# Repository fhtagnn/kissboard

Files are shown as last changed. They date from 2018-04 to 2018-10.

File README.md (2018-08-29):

# kissboard
Hardware and Firmware for the Kissboard keyboard concept by urac/wolf (AdNW user community).

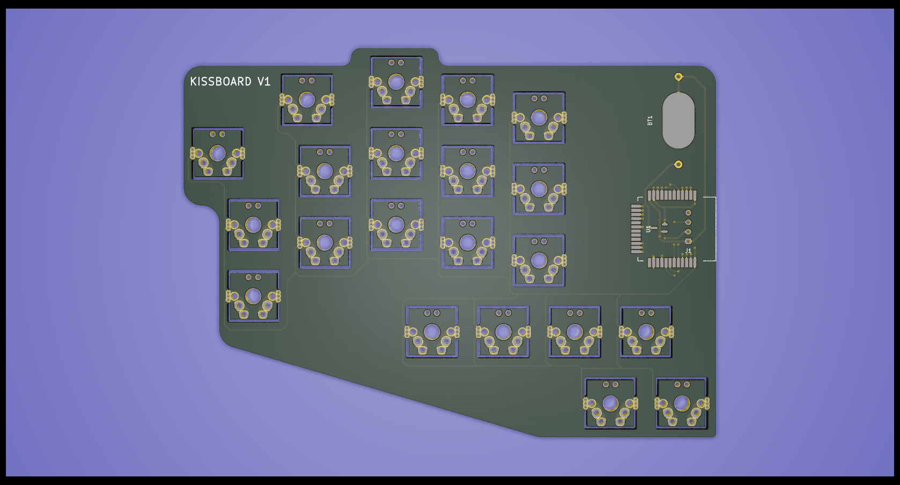
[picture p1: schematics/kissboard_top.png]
Kissboard top view PCB top view
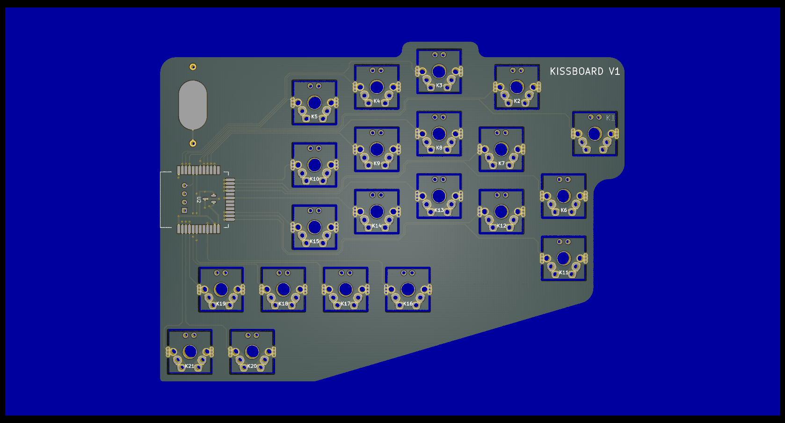
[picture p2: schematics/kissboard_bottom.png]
Kissboard bottom view PCB bottom view


PUQ Layout PUQ Layout overview (http://www.keyboard-layout-editor.com/#/gists/677e3572594a5fb39421fa693f03da17)

Layout explanation
* Middle label: standard tap output
* Bottom Label: double tap output
* Top Label: hold modifier
* Corner labels: Layers

## The idea
The physical key layout is inspired by a 2012 discussion on the german [neo user mailinglist](http://narkive.com/9UhJnT14) about custom keyboards using the [AdNW layout](http://www.adnw.de/). Specifically user urac proposed a minimalistic approach (KISS=keep it stupid simple) simply named [kissboard](https://docs.google.com/document/d/1TQ_BZYoZRW-ZFIaiolPAr9yNul6SBKypeA4ataw5Tz4/edit). Later, AdNW user wolf build a handwired custom board using a modified AdNW variant called PUQ discussed [here](https://groups.google.com/forum/#!topic/adnw/NdMOlERoFa4).

## PCB design
The PCB design was inspired by the [Mitosis Project](https://imgur.com/a/mwTFj) and its [Mitosis hardware](https://github.com/reversebias/mitosis-hardware) created by [reversebias](https://github.com/reversebias). Software implementation is a slightly modified copy of the [Mitosis Firmware](https://github.com/reversebias/mitosis) using [QMK](https://github.com/qmk/qmk_firmware/tree/master/keyboards/mitosis). The original Mitosis design is only available as an altium designer project. I used the freely available [KiCad](http://kicad-pcb.org/) and the converter [altium2kicad](https://github.com/thesourcerer8/altium2kicad) to first convert the layout to kicad, then create footprints of all important components and rebuild the design according to the kissboard/wolf switch layout.

## Firmware
The [Kissboard firmware](https://github.com/fhtagnn/mitosis) is a fork of the [Original Mitosis firmware](https://github.com/reversebias/mitosis) modified to reflect the pin connections used in this layout. Also, I use a [QMK Fork](https://github.com/fhtagnn/qmk_firmware) to implement any changes in the layout.

## Build Log
[Incomplete build log](https://imgur.com/a/pN4dOZB "Imgur Album")

# How to build
## Hardware
Source materials using the information in the BOM folder. Wait...build! :D

## Software
QMK can be build via Docker (below windows call) or per QMK instructions

```docker run -e keymap=default -e keyboard=ergodox_ez --rm -v PATHtoQMK:/qmk:rw edasque/qmk_firmware```

Firmware can be build via Docker (below windows call) or using any arm-gcc build environment. Follow instructions in firmware folder.

```docker run -it -v PATHtoFIRMWARE:/work/kissboard/:rw fhtagnn/kissboard_firmware```

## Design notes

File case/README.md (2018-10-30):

# Kisscase
A 3D printable case for the kissboard made with freecad. Currently two variants are planned: simple and "complex". The simple variant is currently work in progress. The complex one just a concept.

# Simple Variant
The simple variant is meant to work with the V1.0 of the kissboard without any holes for mounting and uses a very simple "clamp" to fix the board in a base.
Kisscase rendering kisscase first render

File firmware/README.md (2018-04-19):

# kissboard Keyboard Firmware
Firmware for Nordic MCUs used in the kissboard Keyboard that is a derivative of the [Mitosis concept](https://github.com/reversebias/mitosis) originally developed by [reversebias](https://github.com/reversebias)

This folder contains sources buildable with the Nordic SDK. To ease building under Windows a Dockerfile is included in the root directory of this repository. It already includes all the steps below including the modification of the SDK file. Usage is very simple if docker is installed. Open a console (Powershell) and type

```docker
docker run -it -v C:\PATH\kissboard\firmware:/work/kissboard/:rw fhtagnn/kissboard_firmware
```

PATH should point to your local copy of the repository. Then 

```
cd kissboard/kissboard-keyboard-basic/custom/armgcc/
make
```

to build the firmware for one of the halves (check config.h). The receiver firmware can be build accordingly.

## Install dependencies

Tested on Ubuntu 16.04.2, but should be able to find alternatives on all distros. 

```
sudo apt install openocd gcc-arm-none-eabi
```

## Download Nordic SDK

Nordic does not allow redistribution of their SDK or components, so download and extract from their site:

https://www.nordicsemi.com/eng/nordic/Products/nRF5-SDK/nRF5-SDK-v12-zip/54291

Firmware written and tested with version 11

```
unzip nRF5_SDK_11.0.0_89a8197.zip  -d nRF5_SDK_11
cd nRF5_SDK_11
```

## Toolchain set-up

A cofiguration file that came with the SDK needs to be changed. Assuming you installed gcc-arm with apt, the compiler root path needs to be changed in /components/toolchain/gcc/Makefile.posix, the line:
```
GNU_INSTALL_ROOT := /usr/local/gcc-arm-none-eabi-4_9-2015q1
```
Replaced with:
```
GNU_INSTALL_ROOT := /usr/
```

## Clone repository
Inside nRF5_SDK_11/
```
git clone https://github.com/fhtagnn/kissboard
```

## Install udev rules
```
sudo cp kissboard/firmware/49-stlinkv2.rules /etc/udev/rules.d/
```
Plug in, or replug in the programmer after this.

## OpenOCD server
The programming header on the side of the keyboard, from top to bottom:
```
SWCLK
SWDIO
GND
3.3V
```
It's best to remove the battery during long sessions of debugging, as charging non-rechargeable lithium batteries isn't recommended.

Launch a debugging session with:
```
openocd -f kissboard/firmware/nrf-stlinkv2.cfg
```
Should give you an output ending in:
```
Info : nrf51.cpu: hardware has 4 breakpoints, 2 watchpoints
```
Otherwise you likely have a loose or wrong wire.

## Manual programming
From the factory, these chips need to be erased:
```
echo reset halt | telnet localhost 4444
echo nrf51 mass_erase | telnet localhost 4444
```
From there, the precompiled binaries can be loaded:
```
echo reset halt | telnet localhost 4444
echo flash write_image `readlink -f precompiled-basic-left.hex` | telnet localhost 4444
echo reset | telnet localhost 4444
```

## Automatic make and programming scripts
To use the automatic build scripts:
```
cd kissboard/firmware/kissboard-keyboard-basic
./program.sh
```
An openocd session should be running in another terminal, as this script sends commands to it.

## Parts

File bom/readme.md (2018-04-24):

# Parts list
Parts required for the kissboard Keyboard

## Keyboard

Line | Description | Quantity | Links
--- | --- | --- | ---
1 | kissboard Keyboard PCB | 4 | [files](https://github.com/fhtagnn/kissboard/tree/master/gerber), [ordering](https://pcbshopper.com)
2 | Core51822 (B) Module | 2 | [direct](http://www.waveshare.com/core51822-b.htm), [aliexpress](https://www.aliexpress.com/w/wholesale-core51822-b.html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)
3 | Si2302 (or any other pin-compatible low voltage nFET) | 2 | [ebay](http://www.ebay.com/sch/i.html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), [digikey](https://www.digikey.com/product-detail/en/vishay-siliconix/SI2302CDS-T1-E3/SI2302CDS-T1-E3CT-ND/3305362)
4 | Right angle 0.1" header (for optional programming header) | 2x 4pin | 
5 | Straight 0.1" header (for battery stabilisers) | 4x 1pin | 
6 | CR2032 Battery | 2 | 
7 | Cherry MX or compatible switches | 46 |
8 | Keycaps | 46x 1U | 

## Receiver
Line | Description | Quantity | Links
--- | --- | --- | ---
1 | Receiver Interface PCB | 1 | [files](https://github.com/reversebias/mitosis-hardware/tree/master/gerbers), [ordering](https://pcbshopper.com)
2 | Core51822 (B) Module | 1 | [direct](http://www.waveshare.com/core51822-b.htm), [aliexpress](https://www.aliexpress.com/w/wholesale-core51822-b.html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)
3 | Arduino Pro Micro | 1 | 
4 | Cree CLVBA-FKA (or any other pin-compatible PLCC-4 LED) | 1 | [digikey](https://www.digikey.com/product-detail/en/cree-inc/CLVBA-FKA-CAEDH8BBB7A363/CLVBA-FKA-CAEDH8BBB7A363CT-ND/2650500)
5 | 1117 3.3v regulator in SOT223 (many types available) | 1 | [digikey](https://www.digikey.com/product-detail/en/diodes-incorporated/AZ1117IH-3.3TRG1/AZ1117IH-3.3TRG1DICT-ND/5699682)
6 | 1206 4.7k resistor array | 2 | [digikey](https://www.digikey.com/product-detail/en/stackpole-electronics-inc/RAVF164DJT4K70/RAVF164DJT4K70CT-ND/2425255)
7 | SMD tactile button (many compatible) | 2 | [digikey](https://www.digikey.com/product-detail/en/c-k/PTS525SM15SMTR2-LFS/CKN9104CT-ND/1146923)
8 | Right angle 0.1" header (for optional programming header) | 1x 4pin | 
9 | Straight 0.1" header (for stacking boards) | 2x 6pin |

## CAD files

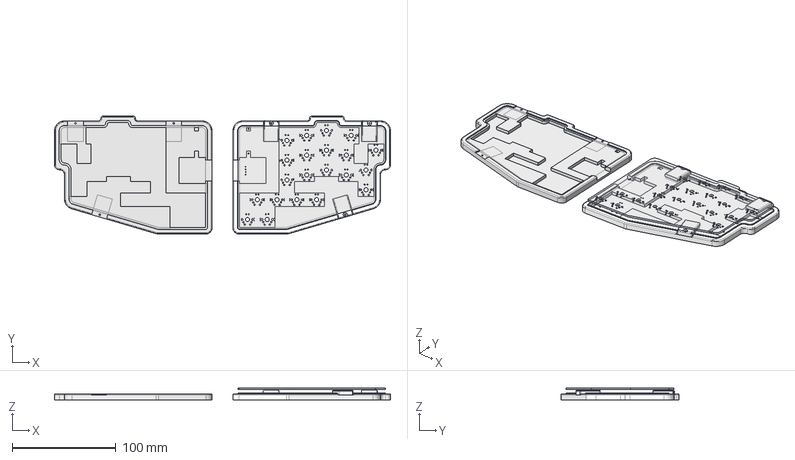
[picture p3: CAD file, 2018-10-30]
case/kisscase_simple_assembly.FCStd
323.6 x 113.7 x 11.7 mm
kisscase_base_right
kissboard_bottom_pcb
kisscase_clamp1
kisscase_clamp002
kisscase_clamp003
kissboard_top_pcb
kisscase_base_left

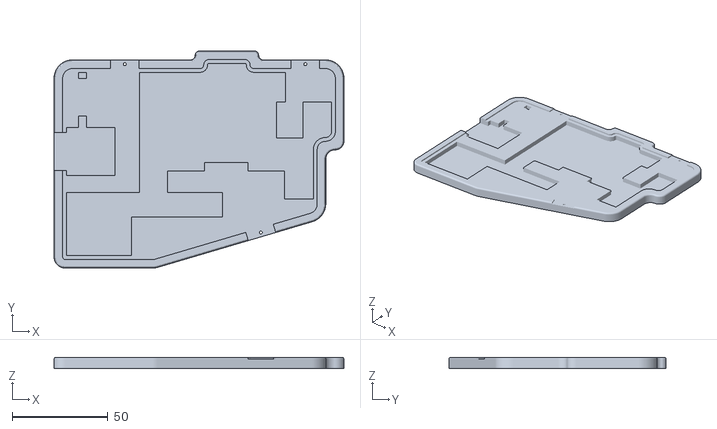
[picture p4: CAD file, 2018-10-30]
case/kisscase_right.stl
151.8 x 113.7 x 6.00

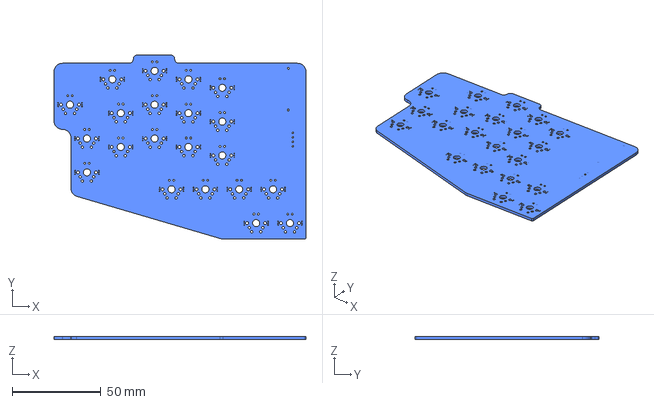
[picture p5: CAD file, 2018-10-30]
kicad-layout/kissboard.step
141.9 x 103.7 x 1.60 mm
Pcb
Step_Models

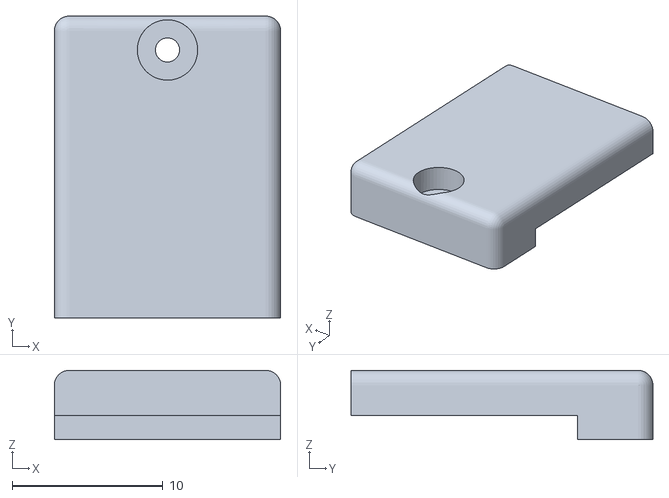
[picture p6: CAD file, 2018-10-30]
case/kisscase_clamp.stl
15.0 x 20.0 x 4.60

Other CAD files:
case/kisscase_left.stl
case/kisscase_simple_both halves.FCStd
case/kisscase_simple_clamp.FCStd

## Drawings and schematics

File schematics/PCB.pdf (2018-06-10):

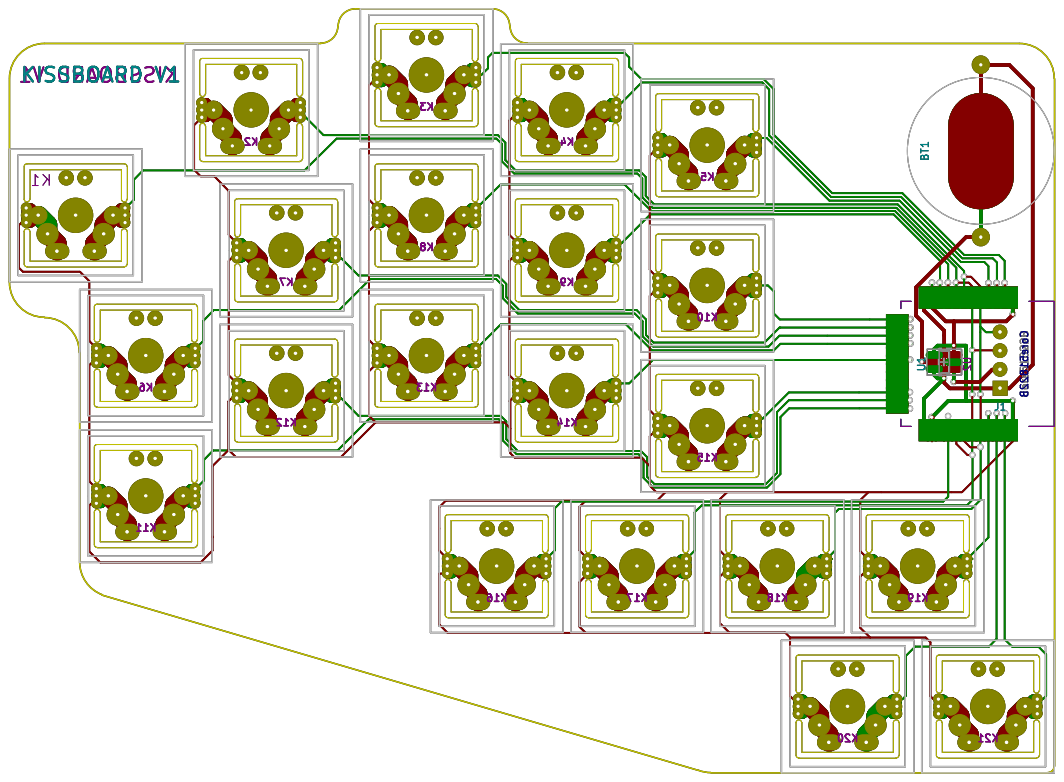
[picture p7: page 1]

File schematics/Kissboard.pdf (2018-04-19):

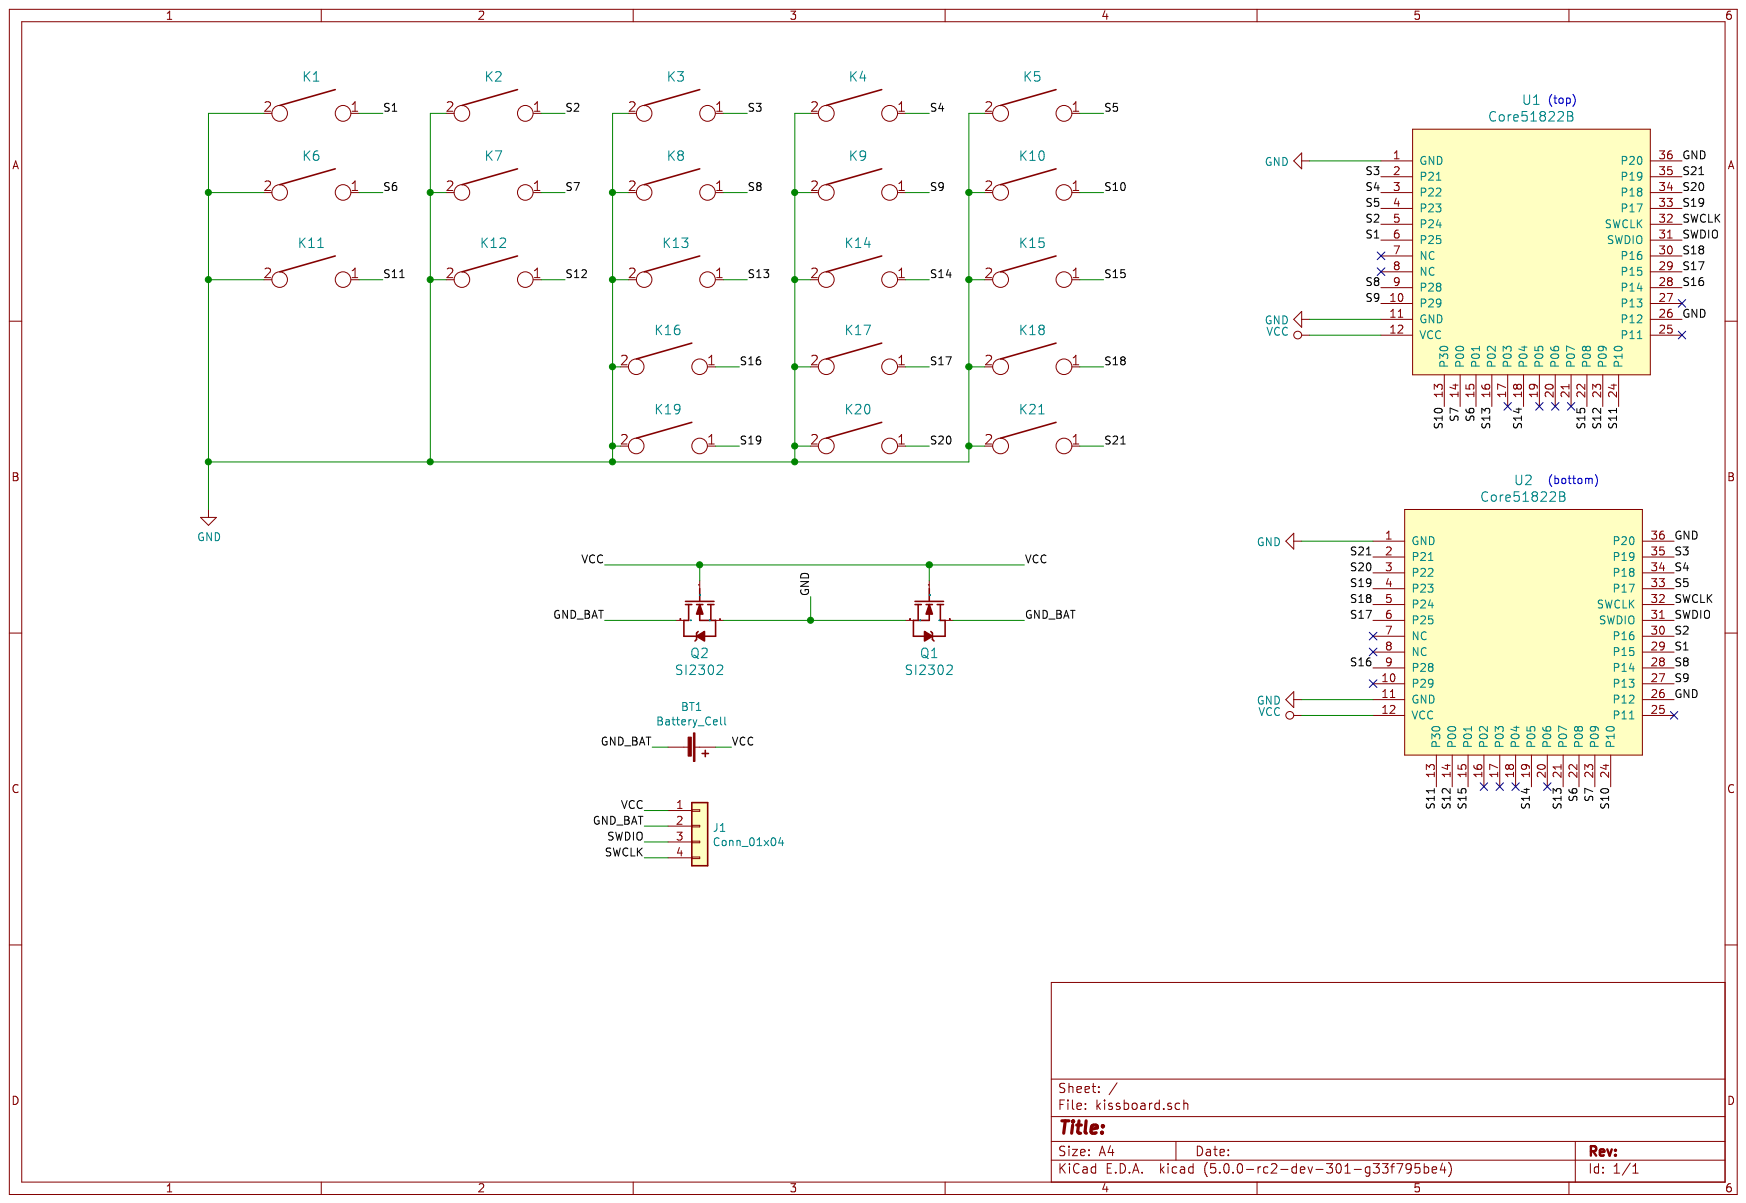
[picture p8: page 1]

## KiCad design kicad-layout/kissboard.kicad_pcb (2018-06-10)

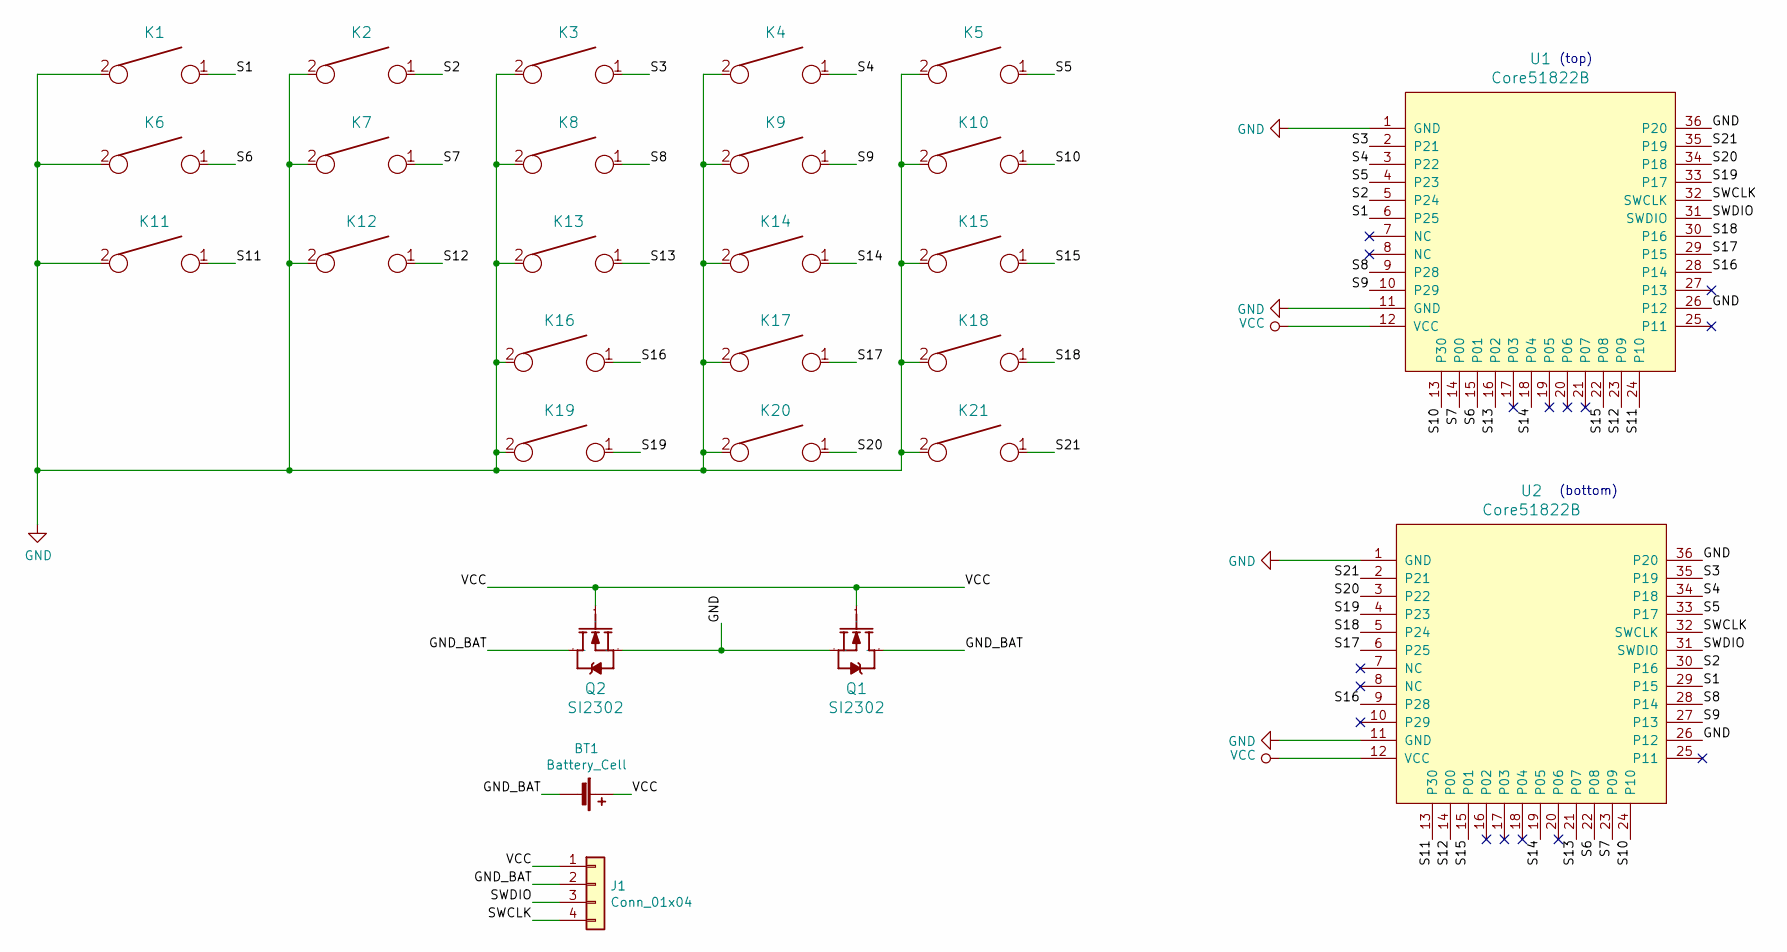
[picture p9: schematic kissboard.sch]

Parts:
BT1: Battery_Cell; battery_contacts
J1: Conn_01x04; programming_port
K1, K2, K3, K4, K5, K6, K7, K8, K9, K10, K11, K12, K13, K14, K15, K16, K17, K18, K19, K20, K21: KEYSW; cherry
Q1, Q2: SI2302; SI3202CDS
U1, U2: Core51822B; Core51822(B)

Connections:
/GND_BAT: BT1.2 (-), J1.2, Q1.3 (D), Q2.3 (D)
/S1: K1.1, U1.6 (P25), U2.29 (P15)
/S2: K2.1, U1.5 (P24), U2.30 (P16)
/S3: K3.1, U1.2 (P21), U2.35 (P19)
/S4: K4.1, U1.3 (P22), U2.34 (P18)
/S5: K5.1, U1.4 (P23), U2.33 (P17)
/S6: K6.1, U1.15 (P01), U2.22 (P08)
/S7: K7.1, U1.14 (P00), U2.23 (P09)
/S8: K8.1, U1.9 (P28), U2.28 (P14)
/S9: K9.1, U1.10 (P29), U2.27 (P13)
/S10: K10.1, U1.13 (P30), U2.24 (P10)
/S11: K11.1, U1.24 (P10), U2.13 (P30)
/S12: K12.1, U1.23 (P09), U2.14 (P00)
/S13: K13.1, U1.16 (P02), U2.21 (P07)
/S14: K14.1, U1.18 (P04), U2.19 (P05)
/S15: K15.1, U1.22 (P08), U2.15 (P01)
/S16: K16.1, U1.28 (P14), U2.9 (P28)
/S17: K17.1, U1.29 (P15), U2.6 (P25)
/S18: K18.1, U1.30 (P16), U2.5 (P24)
/S19: K19.1, U1.33 (P17), U2.4 (P23)
/S20: K20.1, U1.34 (P18), U2.3 (P22)
/S21: K21.1, U1.35 (P19), U2.2 (P21)
/SWCLK: J1.4, U1.32 (SWCLK), U2.32 (SWCLK)
/SWDIO: J1.3, U1.31 (SWDIO), U2.31 (SWDIO)
GND: K1.2, K2.2, K3.2, K4.2, K5.2, K6.2, K7.2, K8.2, K9.2, K10.2, K11.2, K12.2, K13.2, K14.2, K15.2, K16.2, K17.2, K18.2, K19.2, K20.2, K21.2, Q1.2 (S), Q2.2 (S), U1.1 (GND), U1.11 (GND), U1.26 (P12), U1.36 (P20), U2.1 (GND), U2.11 (GND), U2.26 (P12), U2.36 (P20)
VCC: BT1.1 (+), J1.1, Q1.1 (G), Q2.1 (G), U1.12 (VCC), U2.12 (VCC)

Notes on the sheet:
(bottom)
(top)

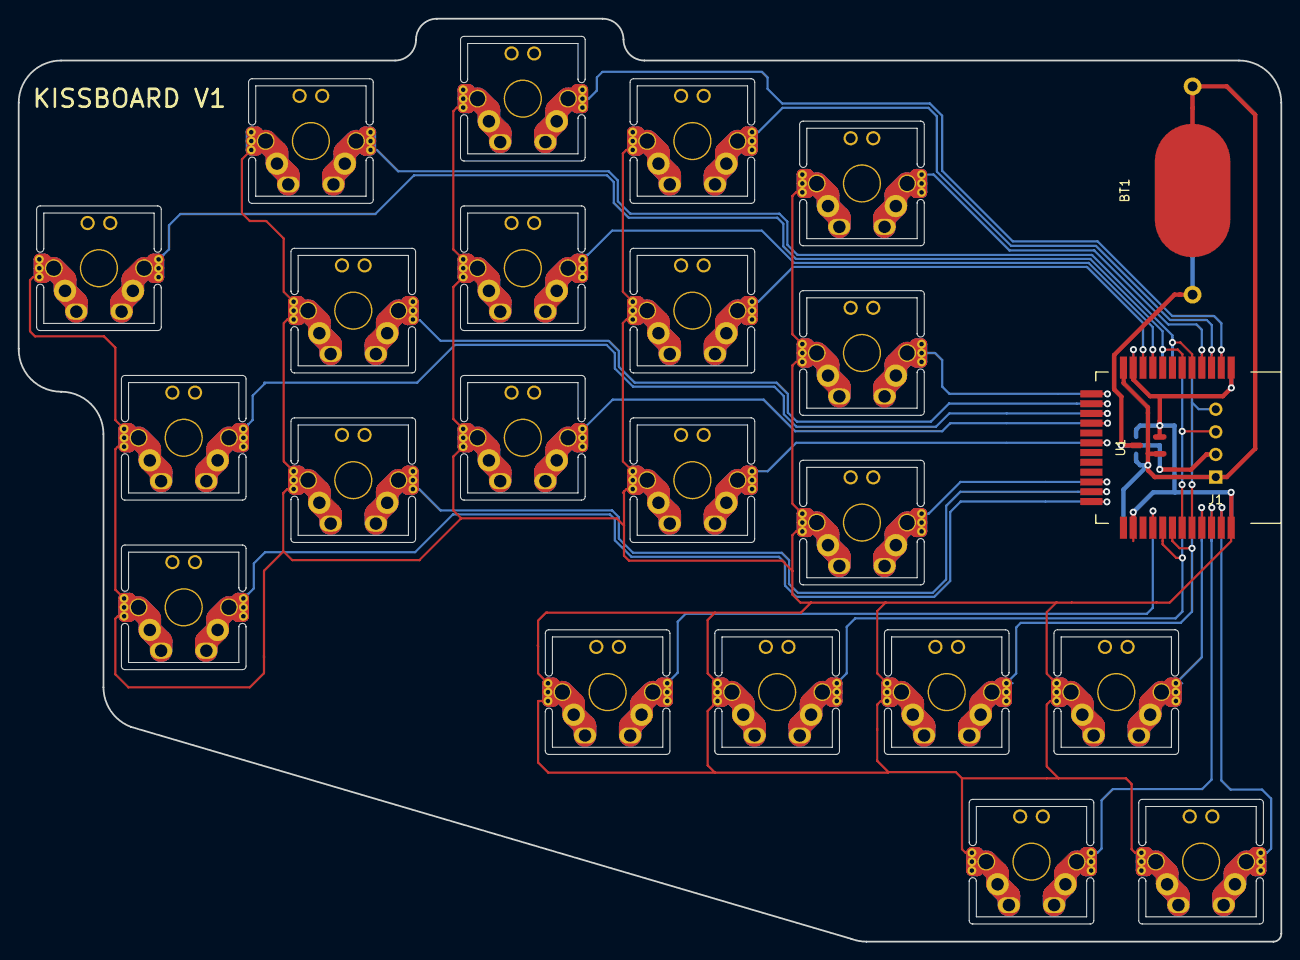
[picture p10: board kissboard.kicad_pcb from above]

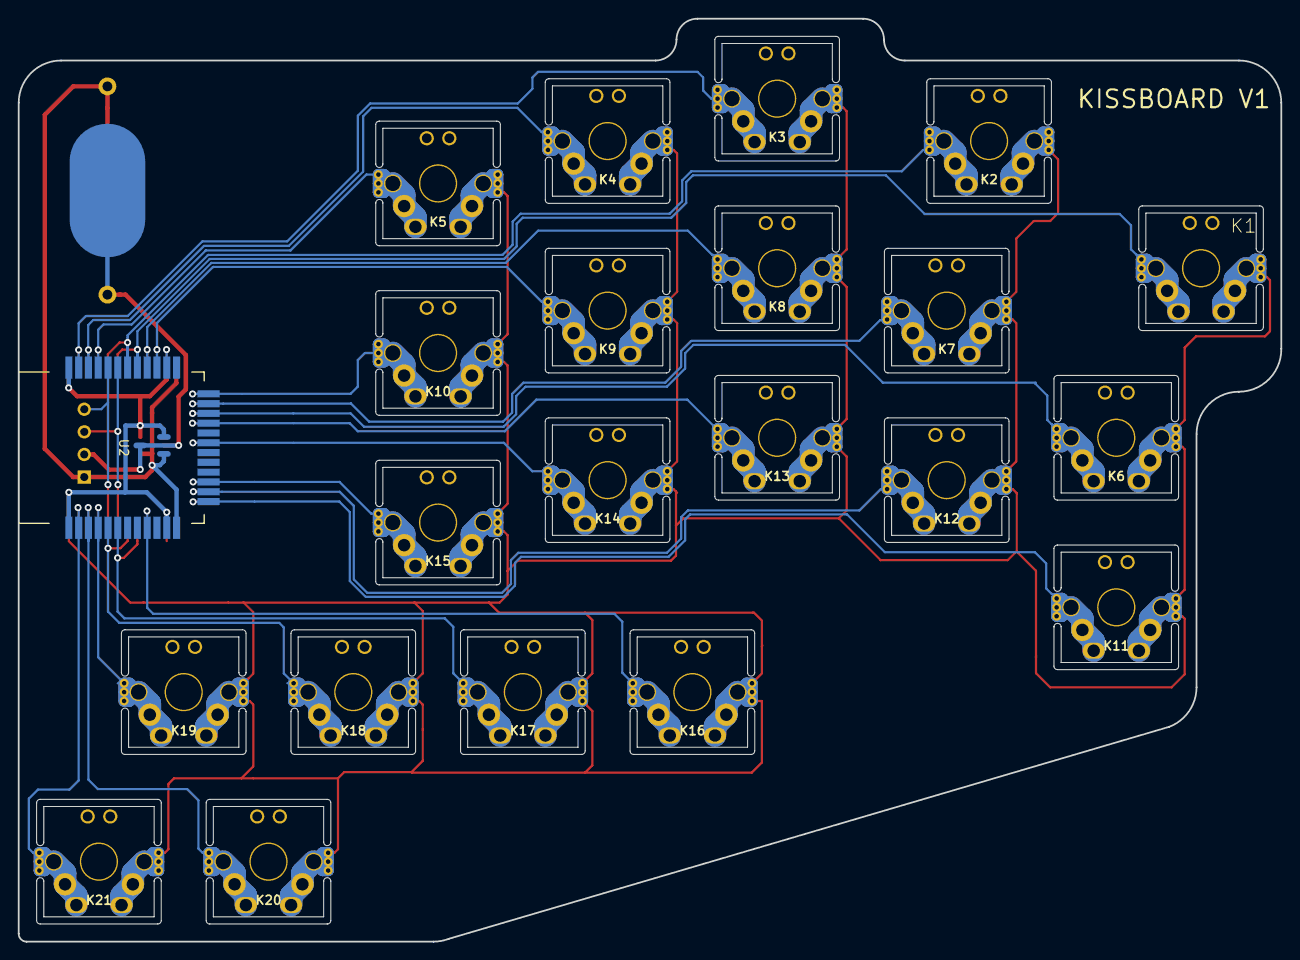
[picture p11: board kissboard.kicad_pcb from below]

Board: 2 copper layers, 141.9 x 103.7 mm, 27 parts (2 on the bottom side), 26 nets.

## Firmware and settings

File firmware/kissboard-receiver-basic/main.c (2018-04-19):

#include <stdbool.h>
#include <stdint.h>
#include <stdio.h>
#include "app_uart.h"
#include "nrf_drv_uart.h"
#include "app_error.h"
#include "nrf_delay.h"
#include "nrf.h"
#include "nrf_gzll.h"

#define MAX_TEST_DATA_BYTES     (15U)                /**< max number of test bytes to be used for tx and rx. */
#define UART_TX_BUF_SIZE 256                         /**< UART TX buffer size. */
#define UART_RX_BUF_SIZE 1                           /**< UART RX buffer size. */


#define RX_PIN_NUMBER  25
#define TX_PIN_NUMBER  24
#define CTS_PIN_NUMBER 23
#define RTS_PIN_NUMBER 22
#define HWFC           false


// Define payload length
#define TX_PAYLOAD_LENGTH 3 ///< 3 byte payload length

// ticks for inactive keyboard
#define INACTIVE 100000

// Binary printing
#define BYTE_TO_BINARY_PATTERN "%c%c%c%c%c"
#define BYTE_TO_BINARY(byte)  \
  (byte & 0x10 ? '#' : '.'), \
  (byte & 0x08 ? '#' : '.'), \
  (byte & 0x04 ? '#' : '.'), \
  (byte & 0x02 ? '#' : '.'), \
  (byte & 0x01 ? '#' : '.') 


// Data and acknowledgement payloads
static uint8_t data_payload_left[NRF_GZLL_CONST_MAX_PAYLOAD_LENGTH];  ///< Placeholder for data payload received from host. 
static uint8_t data_payload_right[NRF_GZLL_CONST_MAX_PAYLOAD_LENGTH];  ///< Placeholder for data payload received from host. 
static uint8_t ack_payload[TX_PAYLOAD_LENGTH];                   ///< Payload to attach to ACK sent to device.
static uint8_t data_buffer[10];

// Debug helper variables
extern nrf_gzll_error_code_t nrf_gzll_error_code;   ///< Error code
static bool init_ok, enable_ok, push_ok, pop_ok, packet_received_left, packet_received_right;
uint32_t left_active = 0;
uint32_t right_active = 0;
uint8_t c;


void uart_error_handle(app_uart_evt_t * p_event)
{
    if (p_event->evt_type == APP_UART_COMMUNICATION_ERROR)
    {
        APP_ERROR_HANDLER(p_event->data.error_communication);
    }
    else if (p_event->evt_type == APP_UART_FIFO_ERROR)
    {
        APP_ERROR_HANDLER(p_event->data.error_code);
    }
}


int main(void)
{
    uint32_t err_code;
    const app_uart_comm_params_t comm_params =
      {
          RX_PIN_NUMBER,
          TX_PIN_NUMBER,
          RTS_PIN_NUMBER,
          CTS_PIN_NUMBER,
          APP_UART_FLOW_CONTROL_DISABLED,
          false,
          UART_BAUDRATE_BAUDRATE_Baud1M
      };

    APP_UART_FIFO_INIT(&comm_params,
                         UART_RX_BUF_SIZE,
                         UART_TX_BUF_SIZE,
                         uart_error_handle,
                         APP_IRQ_PRIORITY_LOW,
                         err_code);

    APP_ERROR_CHECK(err_code);

    // Initialize Gazell
    nrf_gzll_init(NRF_GZLL_MODE_HOST);

    // Addressing
    nrf_gzll_set_base_address_0(0x01020304);
    nrf_gzll_set_base_address_1(0x05060708);
  
    // Load data into TX queue
    ack_payload[0] = 0x55;
    nrf_gzll_add_packet_to_tx_fifo(0, data_payload_left, TX_PAYLOAD_LENGTH);
    nrf_gzll_add_packet_to_tx_fifo(1, data_payload_left, TX_PAYLOAD_LENGTH);

    // Enable Gazell to start sending over the air
    nrf_gzll_enable();

    // main loop
    while (true)
    {
        // detecting received packet from interupt, and unpacking
        if (packet_received_left)
        {
            packet_received_left = false;

            data_buffer[0] = ((data_payload_left[0] & 1<<3) ? 1:0) << 0 |
                             ((data_payload_left[0] & 1<<4) ? 1:0) << 1 |
                             ((data_payload_left[0] & 1<<5) ? 1:0) << 2 |
                             ((data_payload_left[0] & 1<<6) ? 1:0) << 3 |
                             ((data_payload_left[0] & 1<<7) ? 1:0) << 4;

            data_buffer[2] = ((data_payload_left[1] & 1<<6) ? 1:0) << 0 |
                             ((data_payload_left[1] & 1<<7) ? 1:0) << 1 |
                             ((data_payload_left[0] & 1<<0) ? 1:0) << 2 |
                             ((data_payload_left[0] & 1<<1) ? 1:0) << 3 |
                             ((data_payload_left[0] & 1<<2) ? 1:0) << 4;

            data_buffer[4] = ((data_payload_left[1] & 1<<1) ? 1:0) << 0 |
                             ((data_payload_left[1] & 1<<2) ? 1:0) << 1 |
                             ((data_payload_left[1] & 1<<3) ? 1:0) << 2 |
                             ((data_payload_left[1] & 1<<4) ? 1:0) << 3 |
                             ((data_payload_left[1] & 1<<5) ? 1:0) << 4;

            data_buffer[6] = ((data_payload_left[2] & 1<<5) ? 1:0) << 1 |
                             ((data_payload_left[2] & 1<<6) ? 1:0) << 2 |
                             ((data_payload_left[2] & 1<<7) ? 1:0) << 3 |
                             ((data_payload_left[1] & 1<<0) ? 1:0) << 4;

            data_buffer[8] = ((data_payload_left[2] & 1<<1) ? 1:0) << 1 |
                             ((data_payload_left[2] & 1<<2) ? 1:0) << 2 |
                             ((data_payload_left[2] & 1<<3) ? 1:0) << 3 |
                             ((data_payload_left[2] & 1<<4) ? 1:0) << 4;
        }

        if (packet_received_right)
        {
            packet_received_right = false;
            
            data_buffer[1] = ((data_payload_right[0] & 1<<7) ? 1:0) << 0 |
                             ((data_payload_right[0] & 1<<6) ? 1:0) << 1 |
                             ((data_payload_right[0] & 1<<5) ? 1:0) << 2 |
                             ((data_payload_right[0] & 1<<4) ? 1:0) << 3 |
                             ((data_payload_right[0] & 1<<3) ? 1:0) << 4;

            data_buffer[3] = ((data_payload_right[0] & 1<<2) ? 1:0) << 0 |
                             ((data_payload_right[0] & 1<<1) ? 1:0) << 1 |
                             ((data_payload_right[0] & 1<<0) ? 1:0) << 2 |
                             ((data_payload_right[1] & 1<<7) ? 1:0) << 3 |
                             ((data_payload_right[1] & 1<<6) ? 1:0) << 4;

            data_buffer[5] = ((data_payload_right[1] & 1<<5) ? 1:0) << 0 |
                             ((data_payload_right[1] & 1<<4) ? 1:0) << 1 |
                             ((data_payload_right[1] & 1<<3) ? 1:0) << 2 |
                             ((data_payload_right[1] & 1<<2) ? 1:0) << 3 |
                             ((data_payload_right[1] & 1<<1) ? 1:0) << 4;

            data_buffer[7] = ((data_payload_right[1] & 1<<0) ? 1:0) << 0 |
                             ((data_payload_right[2] & 1<<7) ? 1:0) << 1 |
                             ((data_payload_right[2] & 1<<6) ? 1:0) << 2 |
                             ((data_payload_right[2] & 1<<5) ? 1:0) << 3;

            data_buffer[9] = ((data_payload_right[2] & 1<<4) ? 1:0) << 0 |
                             ((data_payload_right[2] & 1<<3) ? 1:0) << 1 |
                             ((data_payload_right[2] & 1<<2) ? 1:0) << 2 |
                             ((data_payload_right[2] & 1<<1) ? 1:0) << 3;
        }

        // checking for a poll request from QMK
        if (app_uart_get(&c) == NRF_SUCCESS && c == 's')
        {
            // sending data to QMK, and an end byte
            nrf_drv_uart_tx(data_buffer,10);
            app_uart_put(0xE0);

            // debugging help, for printing keystates to a serial console
            /*
            for (uint8_t i = 0; i < 10; i++)
            {
                app_uart_put(data_buffer[i]);
            }
            printf(BYTE_TO_BINARY_PATTERN " " \
                   BYTE_TO_BINARY_PATTERN " " \
                   BYTE_TO_BINARY_PATTERN " " \
                   BYTE_TO_BINARY_PATTERN " " \
                   BYTE_TO_BINARY_PATTERN " " \
                   BYTE_TO_BINARY_PATTERN " " \
                   BYTE_TO_BINARY_PATTERN " " \
                   BYTE_TO_BINARY_PATTERN " " \
                   BYTE_TO_BINARY_PATTERN " " \
                   BYTE_TO_BINARY_PATTERN "\r\n", \
                   BYTE_TO_BINARY(data_buffer[0]), \
                   BYTE_TO_BINARY(data_buffer[1]), \
                   BYTE_TO_BINARY(data_buffer[2]), \
                   BYTE_TO_BINARY(data_buffer[3]), \
                   BYTE_TO_BINARY(data_buffer[4]), \
                   BYTE_TO_BINARY(data_buffer[5]), \
                   BYTE_TO_BINARY(data_buffer[6]), \
                   BYTE_TO_BINARY(data_buffer[7]), \
                   BYTE_TO_BINARY(data_buffer[8]), \
                   BYTE_TO_BINARY(data_buffer[9]));   
            nrf_delay_us(100);
            */
        }
        // allowing UART buffers to clear
        nrf_delay_us(10);
        
        // if no packets recieved from keyboards in a few seconds, assume either
        // out of range, or sleeping due to no keys pressed, update keystates to off
        left_active++;
        right_active++;
        if (left_active > INACTIVE)
        {
            data_buffer[0] = 0;
            data_buffer[2] = 0;
            data_buffer[4] = 0;
            data_buffer[6] = 0;
            data_buffer[8] = 0;
            left_active = 0;
        }
        if (right_active > INACTIVE)
        {
            data_buffer[1] = 0;
            data_buffer[3] = 0;
            data_buffer[5] = 0;
            data_buffer[7] = 0;
            data_buffer[9] = 0;
            right_active = 0;
        }
    }
}


// Callbacks not needed in this example.
void nrf_gzll_device_tx_success(uint32_t pipe, nrf_gzll_device_tx_info_t tx_info) {}
void nrf_gzll_device_tx_failed(uint32_t pipe, nrf_gzll_device_tx_info_t tx_info) {}
void nrf_gzll_disabled() {}

// If a data packet was received, identify half, and throw flag
void nrf_gzll_host_rx_data_ready(uint32_t pipe, nrf_gzll_host_rx_info_t rx_info)
{   
    uint32_t data_payload_length = NRF_GZLL_CONST_MAX_PAYLOAD_LENGTH;
    
    if (pipe == 0)
    {
        packet_received_left = true;
        left_active = 0;
        // Pop packet and write first byte of the payload to the GPIO port.
        nrf_gzll_fetch_packet_from_rx_fifo(pipe, data_payload_left, &data_payload_length);
    }
    else if (pipe == 1)
    {
        packet_received_right = true;
        right_active = 0;
        // Pop packet and write first byte of the payload to the GPIO port.
        nrf_gzll_fetch_packet_from_rx_fifo(pipe, data_payload_right, &data_payload_length);
    }
    
    // not sure if required, I guess if enough packets are missed during blocking uart
    nrf_gzll_flush_rx_fifo(pipe);

    //load ACK payload into TX queue
    ack_payload[0] =  0x55;
    nrf_gzll_add_packet_to_tx_fifo(pipe, ack_payload, TX_PAYLOAD_LENGTH);
}

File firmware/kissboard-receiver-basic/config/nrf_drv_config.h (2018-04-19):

/* Copyright (c) 2015 Nordic Semiconductor. All Rights Reserved.
 *
 * The information contained herein is property of Nordic Semiconductor ASA.
 * Terms and conditions of usage are described in detail in NORDIC
 * SEMICONDUCTOR STANDARD SOFTWARE LICENSE AGREEMENT.
 *
 * Licensees are granted free, non-transferable use of the information. NO
 * WARRANTY of ANY KIND is provided. This heading must NOT be removed from
 * the file.
 *
 */

#ifndef NRF_DRV_CONFIG_H
#define NRF_DRV_CONFIG_H

/**
 * Provide a non-zero value here in applications that need to use several
 * peripherals with the same ID that are sharing certain resources
 * (for example, SPI0 and TWI0). Obviously, such peripherals cannot be used
 * simultaneously. Therefore, this definition allows to initialize the driver
 * for another peripheral from a given group only after the previously used one
 * is uninitialized. Normally, this is not possible, because interrupt handlers
 * are implemented in individual drivers.
 * This functionality requires a more complicated interrupt handling and driver
 * initialization, hence it is not always desirable to use it.
 */
#define PERIPHERAL_RESOURCE_SHARING_ENABLED  0

/* CLOCK */
#define CLOCK_ENABLED 0

#if (CLOCK_ENABLED == 1)
#define CLOCK_CONFIG_XTAL_FREQ          NRF_CLOCK_XTALFREQ_Default
#define CLOCK_CONFIG_LF_SRC             NRF_CLOCK_LFCLK_Xtal
#define CLOCK_CONFIG_IRQ_PRIORITY       APP_IRQ_PRIORITY_LOW
#endif

/* GPIOTE */
#define GPIOTE_ENABLED 0

#if (GPIOTE_ENABLED == 1)
#define GPIOTE_CONFIG_USE_SWI_EGU false
#define GPIOTE_CONFIG_IRQ_PRIORITY APP_IRQ_PRIORITY_LOW
#define GPIOTE_CONFIG_NUM_OF_LOW_POWER_EVENTS 1
#endif

/* TIMER */
#define TIMER0_ENABLED 0

#if (TIMER0_ENABLED == 1)
#define TIMER0_CONFIG_FREQUENCY    NRF_TIMER_FREQ_16MHz
#define TIMER0_CONFIG_MODE         TIMER_MODE_MODE_Timer
#define TIMER0_CONFIG_BIT_WIDTH    TIMER_BITMODE_BITMODE_32Bit
#define TIMER0_CONFIG_IRQ_PRIORITY APP_IRQ_PRIORITY_LOW

#define TIMER0_INSTANCE_INDEX      0
#endif

#define TIMER1_ENABLED 0

#if (TIMER1_ENABLED == 1)
#define TIMER1_CONFIG_FREQUENCY    NRF_TIMER_FREQ_16MHz
#define TIMER1_CONFIG_MODE         TIMER_MODE_MODE_Timer
#define TIMER1_CONFIG_BIT_WIDTH    TIMER_BITMODE_BITMODE_16Bit
#define TIMER1_CONFIG_IRQ_PRIORITY APP_IRQ_PRIORITY_LOW

#define TIMER1_INSTANCE_INDEX      (TIMER0_ENABLED)
#endif
 
#define TIMER2_ENABLED 0

#if (TIMER2_ENABLED == 1)
#define TIMER2_CONFIG_FREQUENCY    NRF_TIMER_FREQ_16MHz
#define TIMER2_CONFIG_MODE         TIMER_MODE_MODE_Timer
#define TIMER2_CONFIG_BIT_WIDTH    TIMER_BITMODE_BITMODE_16Bit
#define TIMER2_CONFIG_IRQ_PRIORITY APP_IRQ_PRIORITY_LOW

#define TIMER2_INSTANCE_INDEX      (TIMER1_ENABLED+TIMER0_ENABLED)
#endif

#define TIMER3_ENABLED 0

#if (TIMER3_ENABLED == 1)
#define TIMER3_CONFIG_FREQUENCY    NRF_TIMER_FREQ_16MHz
#define TIMER3_CONFIG_MODE         TIMER_MODE_MODE_Timer
#define TIMER3_CONFIG_BIT_WIDTH    TIMER_BITMODE_BITMODE_16Bit
#define TIMER3_CONFIG_IRQ_PRIORITY APP_IRQ_PRIORITY_LOW

#define TIMER3_INSTANCE_INDEX      (TIMER2_ENABLED+TIMER1_ENABLED+TIMER0_ENABLED)
#endif

#define TIMER4_ENABLED 0

#if (TIMER4_ENABLED == 1)
#define TIMER4_CONFIG_FREQUENCY    NRF_TIMER_FREQ_16MHz
#define TIMER4_CONFIG_MODE         TIMER_MODE_MODE_Timer
#define TIMER4_CONFIG_BIT_WIDTH    TIMER_BITMODE_BITMODE_16Bit
#define TIMER4_CONFIG_IRQ_PRIORITY APP_IRQ_PRIORITY_LOW

#define TIMER4_INSTANCE_INDEX      (TIMER3_ENABLED+TIMER2_ENABLED+TIMER1_ENABLED+TIMER0_ENABLED)
#endif


#define TIMER_COUNT (TIMER0_ENABLED + TIMER1_ENABLED + TIMER2_ENABLED + TIMER3_ENABLED + TIMER4_ENABLED)

/* RTC */
#define RTC0_ENABLED 0

#if (RTC0_ENABLED == 1)
#define RTC0_CONFIG_FREQUENCY    32678
#define RTC0_CONFIG_IRQ_PRIORITY APP_IRQ_PRIORITY_LOW
#define RTC0_CONFIG_RELIABLE     false

#define RTC0_INSTANCE_INDEX      0
#endif

#define RTC1_ENABLED 0

#if (RTC1_ENABLED == 1)
#define RTC1_CONFIG_FREQUENCY    32768
#define RTC1_CONFIG_IRQ_PRIORITY APP_IRQ_PRIORITY_LOW
#define RTC1_CONFIG_RELIABLE     false

#define RTC1_INSTANCE_INDEX      (RTC0_ENABLED)
#endif

#define RTC2_ENABLED 0

#if (RTC2_ENABLED == 1)
#define RTC2_CONFIG_FREQUENCY    32768
#define RTC2_CONFIG_IRQ_PRIORITY APP_IRQ_PRIORITY_LOW
#define RTC2_CONFIG_RELIABLE     false

#define RTC2_INSTANCE_INDEX      (RTC0_ENABLED+RTC1_ENABLED)
#endif


#define RTC_COUNT                (RTC0_ENABLED+RTC1_ENABLED+RTC2_ENABLED)

#define NRF_MAXIMUM_LATENCY_US 2000

/* RNG */
#define RNG_ENABLED 0

#if (RNG_ENABLED == 1)
#define RNG_CONFIG_ERROR_CORRECTION true
#define RNG_CONFIG_POOL_SIZE        8
#define RNG_CONFIG_IRQ_PRIORITY     APP_IRQ_PRIORITY_LOW
#endif

/* PWM */

#define PWM0_ENABLED 0
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

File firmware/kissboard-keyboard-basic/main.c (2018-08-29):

//#define COMPILE_RIGHT
#define COMPILE_LEFT

#include "kissboard.h"
#include "nrf_drv_config.h"
#include "nrf_gzll.h"
#include "nrf_gpio.h"
#include "nrf_delay.h"
#include "nrf_drv_clock.h"
#include "nrf_drv_rtc.h"


/*****************************************************************************/
/** Configuration */
/*****************************************************************************/

const nrf_drv_rtc_t rtc_maint = NRF_DRV_RTC_INSTANCE(0); /**< Declaring an instance of nrf_drv_rtc for RTC0. */
const nrf_drv_rtc_t rtc_deb = NRF_DRV_RTC_INSTANCE(1); /**< Declaring an instance of nrf_drv_rtc for RTC1. */


// Define payload length
#define TX_PAYLOAD_LENGTH 3 ///< 3 byte payload length when transmitting

// Data and acknowledgement payloads
static uint8_t data_payload[TX_PAYLOAD_LENGTH];                ///< Payload to send to Host. 
static uint8_t ack_payload[NRF_GZLL_CONST_MAX_PAYLOAD_LENGTH]; ///< Placeholder for received ACK payloads from Host.

// Debounce time (dependent on tick frequency)
#define DEBOUNCE 5
#define ACTIVITY 500

// Key buffers
static uint32_t keys, keys_snapshot;
static uint32_t debounce_ticks, activity_ticks;
static volatile bool debouncing = false;

// Debug helper variables
static volatile bool init_ok, enable_ok, push_ok, pop_ok, tx_success;  

// Setup switch pins with pullups
static void gpio_config(void)
{
    nrf_gpio_cfg_sense_input(S01, NRF_GPIO_PIN_PULLUP, NRF_GPIO_PIN_SENSE_LOW);
    nrf_gpio_cfg_sense_input(S02, NRF_GPIO_PIN_PULLUP, NRF_GPIO_PIN_SENSE_LOW);
    nrf_gpio_cfg_sense_input(S03, NRF_GPIO_PIN_PULLUP, NRF_GPIO_PIN_SENSE_LOW);
    nrf_gpio_cfg_sense_input(S04, NRF_GPIO_PIN_PULLUP, NRF_GPIO_PIN_SENSE_LOW);
    nrf_gpio_cfg_sense_input(S05, NRF_GPIO_PIN_PULLUP, NRF_GPIO_PIN_SENSE_LOW);
    nrf_gpio_cfg_sense_input(S06, NRF_GPIO_PIN_PULLUP, NRF_GPIO_PIN_SENSE_LOW);
    nrf_gpio_cfg_sense_input(S07, NRF_GPIO_PIN_PULLUP, NRF_GPIO_PIN_SENSE_LOW);
    nrf_gpio_cfg_sense_input(S08, NRF_GPIO_PIN_PULLUP, NRF_GPIO_PIN_SENSE_LOW);
    nrf_gpio_cfg_sense_input(S09, NRF_GPIO_PIN_PULLUP, NRF_GPIO_PIN_SENSE_LOW);
    nrf_gpio_cfg_sense_input(S10, NRF_GPIO_PIN_PULLUP, NRF_GPIO_PIN_SENSE_LOW);
    nrf_gpio_cfg_sense_input(S11, NRF_GPIO_PIN_PULLUP, NRF_GPIO_PIN_SENSE_LOW);
    nrf_gpio_cfg_sense_input(S12, NRF_GPIO_PIN_PULLUP, NRF_GPIO_PIN_SENSE_LOW);
    nrf_gpio_cfg_sense_input(S13, NRF_GPIO_PIN_PULLUP, NRF_GPIO_PIN_SENSE_LOW);
    nrf_gpio_cfg_sense_input(S14, NRF_GPIO_PIN_PULLUP, NRF_GPIO_PIN_SENSE_LOW);
    nrf_gpio_cfg_sense_input(S15, NRF_GPIO_PIN_PULLUP, NRF_GPIO_PIN_SENSE_LOW);
    nrf_gpio_cfg_sense_input(S16, NRF_GPIO_PIN_PULLUP, NRF_GPIO_PIN_SENSE_LOW);
    nrf_gpio_cfg_sense_input(S17, NRF_GPIO_PIN_PULLUP, NRF_GPIO_PIN_SENSE_LOW);
    nrf_gpio_cfg_sense_input(S18, NRF_GPIO_PIN_PULLUP, NRF_GPIO_PIN_SENSE_LOW);
    nrf_gpio_cfg_sense_input(S19, NRF_GPIO_PIN_PULLUP, NRF_GPIO_PIN_SENSE_LOW);
    nrf_gpio_cfg_sense_input(S20, NRF_GPIO_PIN_PULLUP, NRF_GPIO_PIN_SENSE_LOW);
    nrf_gpio_cfg_sense_input(S21, NRF_GPIO_PIN_PULLUP, NRF_GPIO_PIN_SENSE_LOW);
}

// Return the key states, masked with valid key pins
static uint32_t read_keys(void)
{
    return ~NRF_GPIO->IN & INPUT_MASK;
}

// Assemble packet and send to receiver
static void send_data(void)
{
    data_payload[0] = ((keys & 1<<S01) ? 1:0) << 7 | \
                      ((keys & 1<<S02) ? 1:0) << 6 | \
                      ((keys & 1<<S03) ? 1:0) << 5 | \
                      ((keys & 1<<S04) ? 1:0) << 4 | \
                      ((keys & 1<<S05) ? 1:0) << 3 | \
                      ((keys & 1<<S06) ? 1:0) << 2 | \
                      ((keys & 1<<S07) ? 1:0) << 1 | \
                      ((keys & 1<<S08) ? 1:0) << 0;

    data_payload[1] = ((keys & 1<<S09) ? 1:0) << 7 | \
                      ((keys & 1<<S10) ? 1:0) << 6 | \
                      ((keys & 1<<S11) ? 1:0) << 5 | \
                      ((keys & 1<<S12) ? 1:0) << 4 | \
                      ((keys & 1<<S13) ? 1:0) << 3 | \
                      ((keys & 1<<S14) ? 1:0) << 2 | \
                      ((keys & 1<<S15) ? 1:0) << 1 | \
                      ((keys & 1<<S16) ? 1:0) << 0;

    data_payload[2] = ((keys & 1<<S17) ? 1:0) << 7 | \
                      ((keys & 1<<S18) ? 1:0) << 6 | \
                      ((keys & 1<<S19) ? 1:0) << 5 | \
                      ((keys & 1<<S20) ? 1:0) << 4 | \
                      ((keys & 1<<S21) ? 1:0) << 3 | \
                      0 << 2 | \
                      0 << 1 | \
                      0 << 0;

    nrf_gzll_add_packet_to_tx_fifo(PIPE_NUMBER, data_payload, TX_PAYLOAD_LENGTH);
}

// 8Hz held key maintenance, keeping the reciever keystates valid
static void handler_maintenance(nrf_drv_rtc_int_type_t int_type)
{
    send_data();
}

// 1000Hz debounce sampling
static void handler_debounce(nrf_drv_rtc_int_type_t int_type)
{
    // debouncing, waits until there have been no transitions in 5ms (assuming five 1ms ticks)
    if (debouncing)
    {
        // if debouncing, check if current keystates equal to the snapshot
        if (keys_snapshot == read_keys())
        {
            // DEBOUNCE ticks of stable sampling needed before sending data
            debounce_ticks++;
            if (debounce_ticks == DEBOUNCE)
            {
                keys = keys_snapshot;
                send_data();
            }
        }
        else
        {
            // if keys change, start period again
            debouncing = false;
        }
    }
    else
    {
        // if the keystate is different from the last data
        // sent to the receiver, start debouncing
        if (keys != read_keys())
        {
            keys_snapshot = read_keys();
            debouncing = true;
            debounce_ticks = 0;
        }
    }

    // looking for 500 ticks of no keys pressed, to go back to deep sleep
    if (read_keys() == 0)
    {
        activity_ticks++;
        if (activity_ticks > ACTIVITY)
        {
            nrf_drv_rtc_disable(&rtc_maint);
            nrf_drv_rtc_disable(&rtc_deb);
        }
    }
    else
    {
        activity_ticks = 0;
    }

}


// Low frequency clock configuration
static void lfclk_config(void)
{
    nrf_drv_clock_init();

    nrf_drv_clock_lfclk_request(NULL);
}

// RTC peripheral configuration
static void rtc_config(void)
{
    //Initialize RTC instance
    nrf_drv_rtc_init(&rtc_maint, NULL, handler_maintenance);
    nrf_drv_rtc_init(&rtc_deb, NULL, handler_debounce);

    //Enable tick event & interrupt
    nrf_drv_rtc_tick_enable(&rtc_maint,true);
    nrf_drv_rtc_tick_enable(&rtc_deb,true);

    //Power on RTC instance
    //nrf_drv_rtc_enable(&rtc_maint);
    //nrf_drv_rtc_enable(&rtc_deb);
}
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

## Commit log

2018-04-05 intial commit of kissboard kicad files and readme
    [kissboard-B.Cu.gbl, kissboard-B.Mask.gbs, kissboard-B.Paste.gbp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]
2018-04-05 Reshaping of PCB. Cleaning of old tracks in the works...
    [kissboard.kicad_pcb]
2018-04-07 Completed cleaning of tracks for new placement and added updated pictures.
    [kissboard.kicad_pcb]
2018-04-08 traces complete, all files updated, gerber.zip added
    [kissboard-B.Cu.gbl, kissboard-B.Mask.gbs, kissboard-B.Paste.gbp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]
2018-04-08 Adjusted edge cut, updated pictures and pdf prints
    [kissboard.kicad_pcb]
2018-04-08 Updated gerber files and added zip file
2018-04-18 Fixed wrong connection of S16 on the bottom layer
    [kissboard-B.Cu.gbl, kissboard-B.Mask.gbs, kissboard-B.Paste.gbp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]
2018-04-19 Copied mitosis firmware fork into the kissboard repository
    [nrf-stlink.cfg]
2018-04-24 added bill of materials
2018-06-05 Layout adjusted: lower pinky finger column and straight thumb row
    [kissboard-B.Cu.gbl, kissboard-B.Mask.gbs, kissboard-B.Paste.gbp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]
2018-06-05 tiny adjustment of a single track
    [kissboard-B.Cu.gbl, kissboard-B.Mask.gbs, kissboard-B.Paste.gbp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]
2018-06-10 Fixed thumb row: moved half key in towards thumb
    [kissboard-B.Cu.gbl, kissboard-B.Mask.gbs, kissboard-B.Paste.gbp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]
2018-08-29 Corrected pin/key assigment to match expected key places for QMK
    [main.c]
2018-10-30 corrected typo in the pin assignement. Left key 16 was not assigned, but key 19 twice.
2018-10-30 First commit for the kisscase files.
    [kissboard.step, kisscase_clamp.stl, kisscase_left.stl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]
